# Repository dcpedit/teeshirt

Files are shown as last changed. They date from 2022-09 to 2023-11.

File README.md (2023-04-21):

<p align="center">
  teeshirt_logo
</p>

# TeeShirt Keyboard

teeshirt-6

TeeShirt is a ergonomic monoblock keyboard with a one-size-fits-some PCB design that supports 3 different sized builds: S, M, and L.

## Features

* [Size S](https://github.com/dcpedit/teeshirt/tree/master/small-build): case-less barebones keyboard build
* [Size M](https://github.com/dcpedit/teeshirt/tree/master/medium-build): custom slim acrylic case build
* [Size L](https://github.com/dcpedit/teeshirt/tree/master/large-build): standard 60% case (GH60 compatible) build
* Supports 1.5u and 1.25u thumb keys to reduce gap between keycaps
* Spacebars can be 2u or 1.5u for stab-less builds
* Center key can be swapped out for a rotary encoder
* Supports 128x32 OLED display
* Utilizes hot swap sockets
* Uses ProMicro MCU footprint: Elite-C, Nice!Nano, etc.

## Sponsors

The first revision of the PCB was sponsored by PCBWay, so a huge thanks to them for helping get this project off the ground.  Their KiCad plugin made it super easy to send the design directly to their site, where you can place the order and have it shipped out with just a few clicks.

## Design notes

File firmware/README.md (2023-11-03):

# TeeShirt Firmware

## Vial
Binary: `dcpedit_teeshirt_vial_fancy.hex`

Source: https://github.com/dcpedit/vial-qmk-dev/tree/vial/keyboards/dcpedit/teeshirt

## ZMK

Binary: `zmk.uf2`

Source: https://github.com/dcpedit/zmk/tree/dcpedit/app/boards/shields/teeshirt

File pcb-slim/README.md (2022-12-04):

# TeeShirt PCB

pcb-slim

The PCB automatically applies power to the VBUS pin, but if you want to also send power to the RAW pin (#24), you can short JP1.

pcb-back-1

If you're relocating the USB port to the upper left of the PCB for the large sized (60%) builds, make sure you also soldering in 5.1k resistors, as well as connecting the data pins on the PCB (D+/D-) to the data pins/pads to the MCU with wires.

bottom-2

For the small builds, the MCU can be mounted on the top side with headers.

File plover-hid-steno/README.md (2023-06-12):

# Small TeeShirt build and Plover

Keymap

I've put together some documentation for those who wanted to play around with stenography.  It took some tinkering to get ZMK working with Plover, so hopefully these instructions will be helpful to those who are looking to accomplish the same thing.

## ZMK firmware

https://github.com/dcpedit/zmk-plover/tree/plover-hid-hog-attempt/app/boards/shields/teeshirt

Make sure you're cloning the `plover-hid-hog-attempt` branch:
```
git clone -b plover-hid-hog-attempt https://github.com/dcpedit/zmk-plover
```

This is a fork of dnaq's implementation of the Plover HID protocol in ZMK.  You can read about it in the [official pull request here.](https://github.com/zmkfirmware/zmk/pull/962)  You can also clone his fork directly with the following command:
```
git clone -b plover-hid-hog-attempt https://github.com/dnaq/zmk
```

Follow the [ZMK environment setup](https://zmk.dev/docs/development/setup).  I highly recommend using VS Code & Docker.  For MacOS users, you may need to update `.devcontainer/DockerFile` with the following line for the container to start:
```
FROM --platform=linux/x86_64 docker.io/zmkfirmware/zmk-dev-arm:3.0
```

To run the build:
```
cd app
west build -b nice_nano_v2 -- -DSHIELD=teeshirt
```
Binary will be located here.
```
app/build/zephyr/zmk.uf2
```

If you're using a TeeShirt board, you can use my precompiled binary (`zmk.uf2`)

After loading the firmware, you can test it with the following website (by jthlim):
https://lim.au/#/software/plover-hid

## Macs with Intel chip

Plover requires the `hidapi` package, so you will need to install it with [Homebrew](https://brew.sh/).

```
brew install hidapi
```

## Macs with ARM chip (M1, M2)

The ARM version of `hidapi` package will not work, so you will need to install the Intel (x86) version of Homebrew and hidapi  [(source)](https://gist.github.com/progrium/b286cd8c82ce0825b2eb3b0b3a0720a0).

```
$ arch -x86_64 zsh
$ /bin/bash -c "$(curl -fsSL https://raw.githubusercontent.com/Homebrew/install/HEAD/install.sh)"
```

Add the following to your `~/.zshrc` file:
```
if [ "$(arch)" = "arm64" ]; then
    eval "$(/opt/homebrew/bin/brew shellenv)"
else
    eval "$(/usr/local/bin/brew shellenv)"
fi
```

Then install `hidapi`
```
$ source ~/.zshrc
$ brew install hidapi
```

## Plover software

Now download and install the Plover software: https://www.openstenoproject.org/plover/

If you're on MacOS, add "Plover" in System Settings > Security and Privacy > Input Monitoring.  Then disconnect and forget the bluetooth keyboard and reboot macOS. Clear the bluetooth setting on your keyboard and repeat the pairing process.  If that doesn't work, you may need to reflash.

Security and Privacy

## Plover HID Plugin

Download or clone https://github.com/dnaq/plover-machine-hid

Then switch to the directory where the plugin files are located.

```
cd plover-machine-hid
```

Follwing the [Plover instructions for installing plugins](https://plover.readthedocs.io/en/latest/plugins.html), run the command below (examples are for a Mac)

```
/Applications/Plover.app/Contents/MacOS/Plover -s plover_plugins install -e .
```

To list installed plugins

```
/Applications/Plover.app/Contents/MacOS/Plover -s plover_plugins list
```

## Configure Plover

Start the Plover application, click the **Configure** button, and then go to the **Machine** tab.  Select `Plover HID` in the **Machine** dropdown.

Double click on each of the **Action** cells in the right column and select the action that matches the left column.  Then click the **OK** button to go back to the main screen.

Configure

Select the `Plover HID` Machine and then click select `Enable`.

Plover-HID

## Reconnect plugin

Since ZMK boards will go to sleep after a period of inactivity, this reconnect plover plugin makes the experience more seamless when it wakes again:

https://github.com/tschulte/plover_auto_reconnect_machine

## Start typing!

And that's it!  The middle button on the TeeShirt will toggle the Plover layer on and off.  Here's a good resource if you're just starting out with Plover:

https://sites.google.com/site/learnplover/home

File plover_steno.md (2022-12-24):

# TeeShirt and Plover

I've put together some documentation for those who wanted to play around with stenography.  It took some tinkering to get ZMK working with Plover, so hopefully these instructions will save you some time.

## ZMK firmware

https://github.com/dcpedit/zmk-plover

This is a fork of dnaq's implementation of the Plover HID protocol in ZMK.  You can read about it in the [official pull request here.](https://github.com/zmkfirmware/zmk/pull/962)

The precompiled binary is in `firmware/plover_hid`.

After loading the firmware, you can test it with the following site:
https://lim.au/#/software/plover-hid

## Macs with Intel chip

Plover requires the `hidapi` package, so you will need to install it with [Homebrew](https://brew.sh/).

```
brew install hidapi
```

## Mac with ARM chip (M1, M2)

The ARM version of `hidapi` package will not work, so you will need to install the Intel (x86) version of Homebrew and hidapi.

```
$ arch -x86_64 zsh
$ /bin/bash -c "$(curl -fsSL https://raw.githubusercontent.com/Homebrew/install/HEAD/install.sh)"
```

```
$ brew install hidapi
```

## Plover software

Now download and install the Plover software: https://www.openstenoproject.org/plover/

## Plover HID Plugin

Download or clone https://github.com/dnaq/plover-machine-hid

Then switch to the directory where the plugin files are located.

```
cd plover-machine-hid
```

Follwing the [Plover instructions for installing plugins](https://plover.readthedocs.io/en/latest/plugins.html), run the command below (examples are for a Mac)

```
/Applications/Plover.app/Contents/MacOS/Plover -s plover_plugins install -e .
```

To list installed plugins

```
/Applications/Plover.app/Contents/MacOS/Plover -s plover_plugins list
```

## Configure Plover

Start the Plover application and click the **Configure** button and then go to the **Machine** tab.  Select **Plover HID** in the Machine dropdown.

Double click on each of the Action cells in the right column and select the action that matches the left column.  Then click the **OK** button to go back to the main screen.

Select the `Plover HID` machine and then click select **Enable**

Then

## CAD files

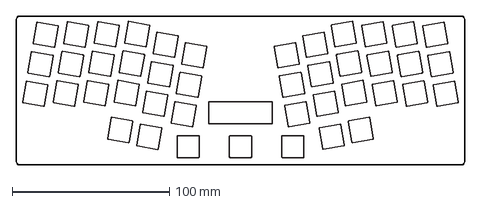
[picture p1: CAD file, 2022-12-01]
large-build/case-full.dxf
285.0 x 94.6 mm

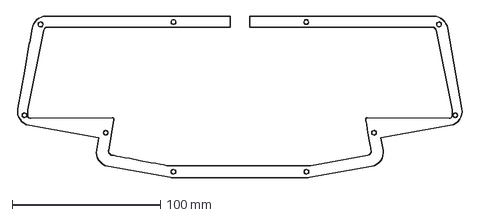
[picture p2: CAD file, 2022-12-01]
medium-build/case-slim.dxf
300.7 x 109.0 mm

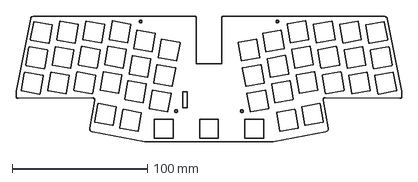
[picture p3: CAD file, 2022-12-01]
small-build/bare-stacked.dxf
285.0 x 92.5 mm

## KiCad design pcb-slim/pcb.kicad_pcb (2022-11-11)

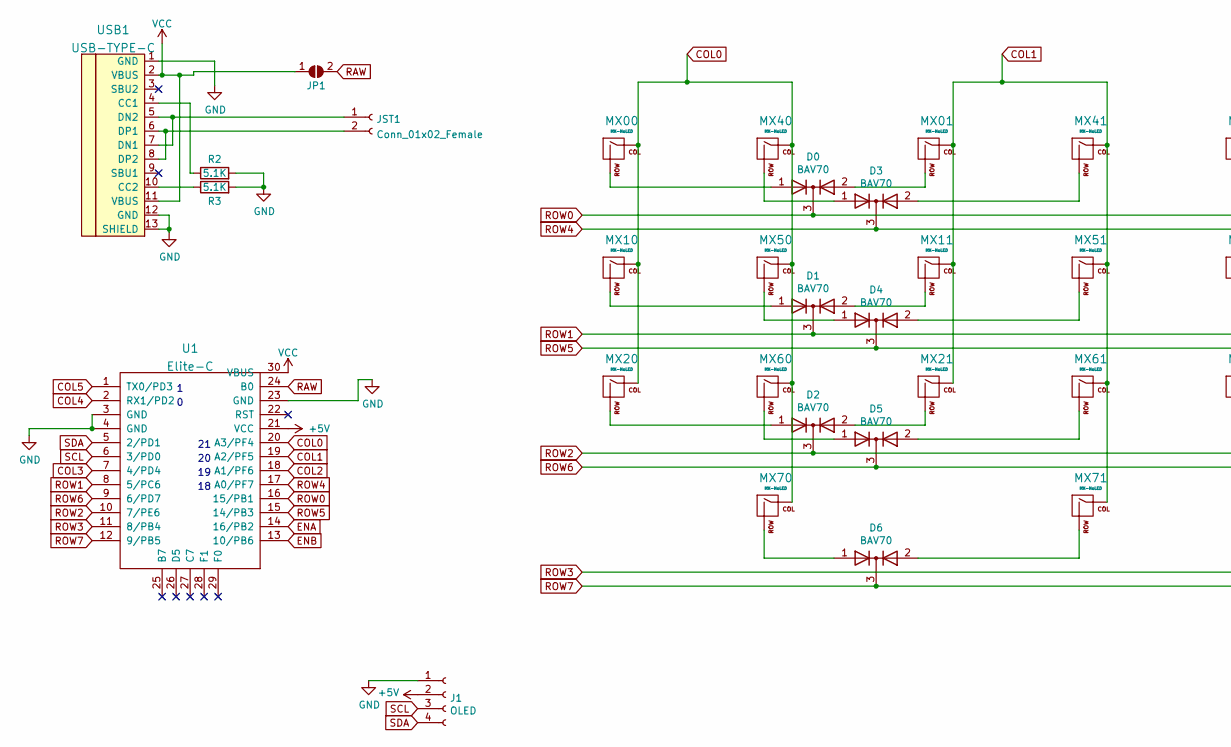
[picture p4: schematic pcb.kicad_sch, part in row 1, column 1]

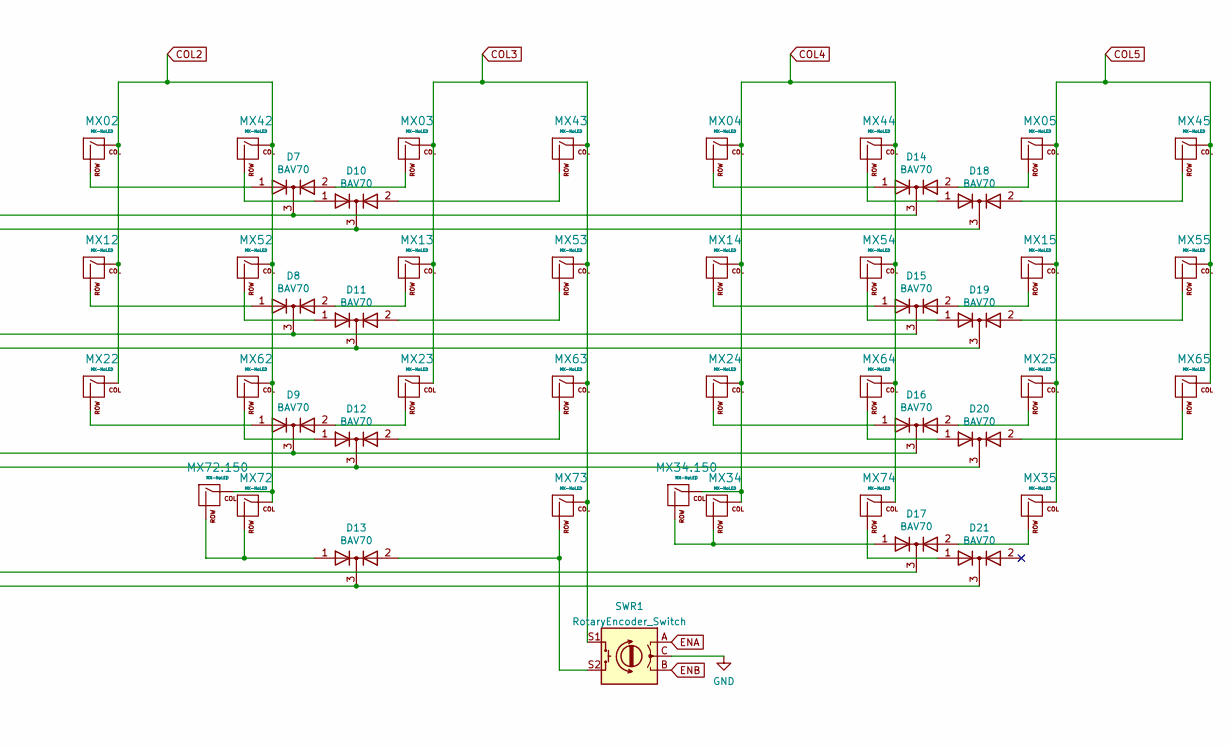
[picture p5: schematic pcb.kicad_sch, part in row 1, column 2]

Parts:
D0, D1, D2, D3, D4, D5, D6, D7, D8, D9, D10, D11, D12, D13, D14, D15, D16, D17, D18, D19, D20, D21: BAV70; SOT-23_Handsoldering
J1: OLED; SSD1306_OLED
JP1: SolderJumper_2_Open; SolderJumper-2_P1.3mm_Open_RoundedPad1.0x1.5mm
JST1: Conn_01x02_Female
MX00, MX01, MX02, MX03, MX04, MX05, MX10, MX11, MX12, MX13, MX14, MX15, MX20, MX21, MX22, MX23, MX24, MX25, MX34, MX34.150, MX35, MX40, MX41, MX42, MX43, MX44, MX45, MX50, MX51, MX52, MX53, MX54, MX55, MX60, MX61, MX62, MX63, MX64, MX65, MX70, MX71, MX72, MX72.150, MX73, MX74: MX-NoLED; MXOnly-1U-NoLED
R2, R3: 5.1K; R_0805_2012Metric_Pad1.20x1.40mm_HandSolder; LCSC C27834
SWR1: RotaryEncoder_Switch
U1: Elite-C
USB1: USB-TYPE-C

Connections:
+5V: J1.2, U1.21 (VCC)
COL0: MX00.1 (COL), MX10.1 (COL), MX20.1 (COL), MX40.1 (COL), MX50.1 (COL), MX60.1 (COL), MX70.1 (COL), U1.20 (A3/PF4)
COL1: MX01.1 (COL), MX11.1 (COL), MX21.1 (COL), MX41.1 (COL), MX51.1 (COL), MX61.1 (COL), MX71.1 (COL), U1.19 (A2/PF5)
COL2: MX02.1 (COL), MX12.1 (COL), MX22.1 (COL), MX42.1 (COL), MX52.1 (COL), MX62.1 (COL), MX72.1 (COL), MX72.150.1 (COL), U1.18 (A1/PF6)
COL3: MX03.1 (COL), MX13.1 (COL), MX23.1 (COL), MX43.1 (COL), MX53.1 (COL), MX63.1 (COL), MX73.1 (COL), SWR1.S1, U1.7 (4/PD4)
COL4: MX04.1 (COL), MX14.1 (COL), MX24.1 (COL), MX34.1 (COL), MX34.150.1 (COL), MX44.1 (COL), MX54.1 (COL), MX64.1 (COL), MX74.1 (COL), U1.2 (RX1/PD2)
COL5: MX05.1 (COL), MX15.1 (COL), MX25.1 (COL), MX35.1 (COL), MX45.1 (COL), MX55.1 (COL), MX65.1 (COL), U1.1 (TX0/PD3)
ENA: SWR1.A, U1.14 (16/PB2)
ENB: SWR1.B, U1.13 (10/PB6)
GND: J1.1, R2.2, R3.2, SWR1.C, U1.3 (GND), U1.4 (GND), U1.23 (GND), USB1.1 (GND), USB1.12 (GND), USB1.13 (SHIELD)
unnamed: D0.1 (A), MX00.2 (ROW)
unnamed: D0.2 (A), MX01.2 (ROW)
unnamed: D1.1 (A), MX10.2 (ROW)
unnamed: D1.2 (A), MX11.2 (ROW)
unnamed: D2.1 (A), MX20.2 (ROW)
unnamed: D2.2 (A), MX21.2 (ROW)
unnamed: D3.1 (A), MX40.2 (ROW)
unnamed: D3.2 (A), MX41.2 (ROW)
unnamed: D4.1 (A), MX50.2 (ROW)
unnamed: D4.2 (A), MX51.2 (ROW)
unnamed: D5.1 (A), MX60.2 (ROW)
unnamed: D5.2 (A), MX61.2 (ROW)
unnamed: D6.1 (A), MX70.2 (ROW)
unnamed: D6.2 (A), MX71.2 (ROW)
unnamed: D7.1 (A), MX02.2 (ROW)
unnamed: D7.2 (A), MX03.2 (ROW)
unnamed: D8.1 (A), MX12.2 (ROW)
unnamed: D8.2 (A), MX13.2 (ROW)
unnamed: D9.1 (A), MX22.2 (ROW)
unnamed: D9.2 (A), MX23.2 (ROW)
unnamed: D10.1 (A), MX42.2 (ROW)
unnamed: D10.2 (A), MX43.2 (ROW)
unnamed: D11.1 (A), MX52.2 (ROW)
unnamed: D11.2 (A), MX53.2 (ROW)
unnamed: D12.1 (A), MX62.2 (ROW)
unnamed: D12.2 (A), MX63.2 (ROW)
unnamed: D13.1 (A), MX72.2 (ROW), MX72.150.2 (ROW)
unnamed: D13.2 (A), MX73.2 (ROW), SWR1.S2
unnamed: D14.1 (A), MX04.2 (ROW)
unnamed: D14.2 (A), MX05.2 (ROW)
unnamed: D15.1 (A), MX14.2 (ROW)
unnamed: D15.2 (A), MX15.2 (ROW)
unnamed: D16.1 (A), MX24.2 (ROW)
unnamed: D16.2 (A), MX25.2 (ROW)
unnamed: D17.1 (A), MX34.2 (ROW), MX34.150.2 (ROW)
unnamed: D17.2 (A), MX35.2 (ROW)
unnamed: D18.1 (A), MX44.2 (ROW)
unnamed: D18.2 (A), MX45.2 (ROW)
unnamed: D19.1 (A), MX54.2 (ROW)
unnamed: D19.2 (A), MX55.2 (ROW)
unnamed: D20.1 (A), MX64.2 (ROW)
unnamed: D20.2 (A), MX65.2 (ROW)
unnamed: D21.1 (A), MX74.2 (ROW)
unnamed: R2.1, USB1.4 (CC1)
unnamed: R3.1, USB1.10 (CC2)
unnamed: JST1.1, USB1.5 (DN2), USB1.7 (DN1)
unnamed: JST1.2, USB1.6 (DP1), USB1.8 (DP2)
RAW: JP1.2 (B), U1.24 (B0)
ROW0: D0.3 (K), D7.3 (K), D14.3 (K), U1.16 (15/PB1)
ROW1: D1.3 (K), D8.3 (K), D15.3 (K), U1.8 (5/PC6)
ROW2: D2.3 (K), D9.3 (K), D16.3 (K), U1.10 (7/PE6)
ROW3: D17.3 (K), U1.11 (8/PB4)
ROW4: D3.3 (K), D10.3 (K), D18.3 (K), U1.17 (A0/PF7)
ROW5: D4.3 (K), D11.3 (K), D19.3 (K), U1.15 (14/PB3)
ROW6: D5.3 (K), D12.3 (K), D20.3 (K), U1.9 (6/PD7)
ROW7: D6.3 (K), D13.3 (K), D21.3 (K), U1.12 (9/PB5)
SCL: J1.3, U1.6 (3/PD0)
SDA: J1.4, U1.5 (2/PD1)
VCC: JP1.1 (A), U1.30 (VBUS), USB1.2 (VBUS), USB1.11 (VBUS)

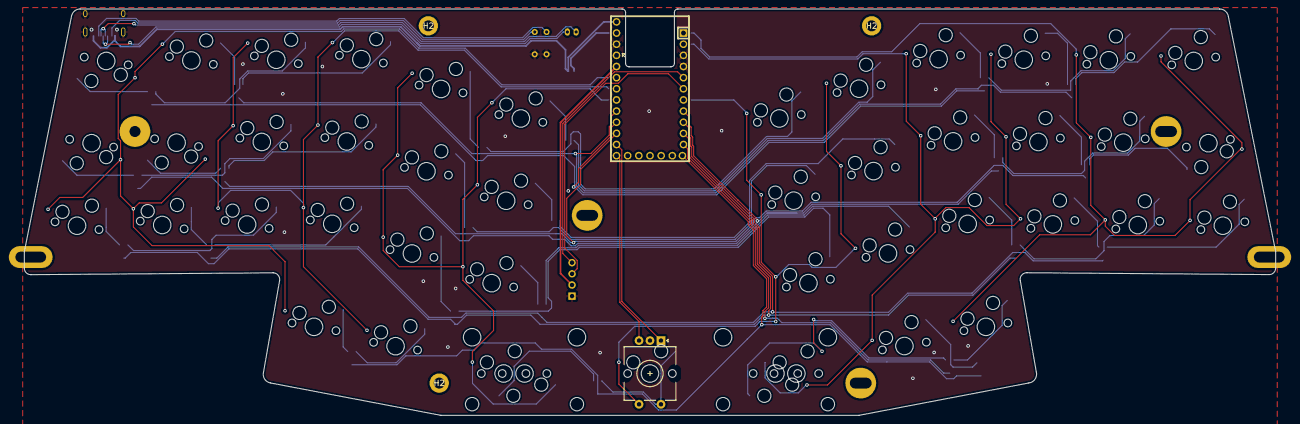
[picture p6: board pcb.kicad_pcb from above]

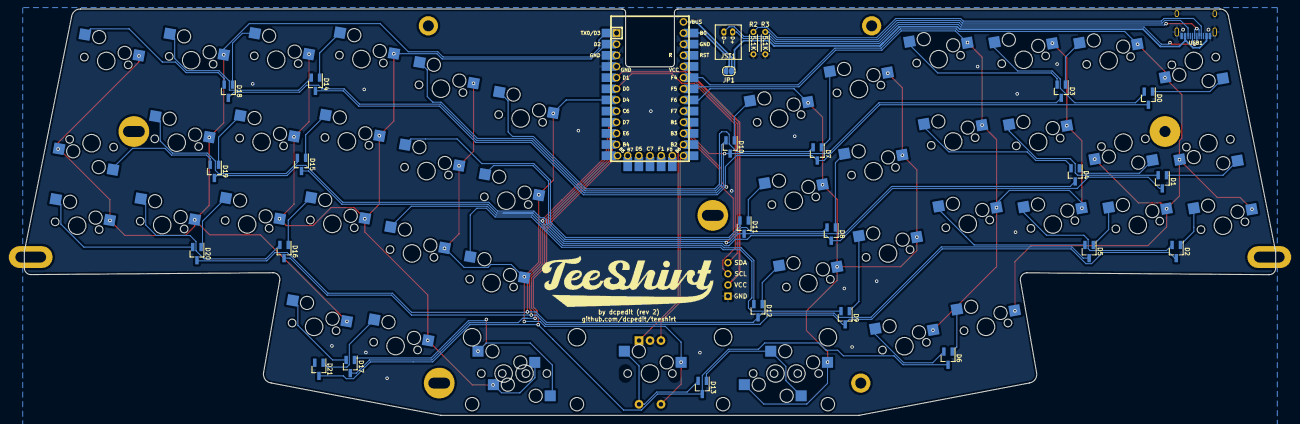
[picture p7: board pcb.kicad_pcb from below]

Board: 2 copper layers, 285.0 x 92.5 mm, 84 parts (28 on the bottom side), 69 nets.

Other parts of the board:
H2, H2#2, H2#3: (no value)
HOLE: VAL**; PKRH
HOLE#2, HOLE#4: VAL**; PKRH
HOLE#3, HOLE#5: VAL**; PKRHSL
HOLE#6: VAL**; PKRHC

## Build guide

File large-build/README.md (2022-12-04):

# Large Build Guide

Large-1

This guide is based on the exact build that is pictured above.  Feel free to customize it to your fit your needs.

## Components

| Part | Count | Description |
| ---- | ----- | --- |
| Elite-C | 1 | Microcontroller |
| USB port | 1 | TYPE-C-31-M-12 |
| Wires | 2 | Connects data lines to PCB |
| Pin | 1 | For power connection |
| 5.1k resistor| 2 | Through hole pulldown resistors for USB-C |
| Diodes | 22 | BAV70 SMD |
| Switch sockets | 42 | Kailh hot swap sockets |
| OLED | 1 | SSD1306 128x32 |
| Rotary encoder | 1 | EC11 |
| Encoder knob | 1 | No more than 20mm diameter |
| Plate foam | 1 | 3.5mm (or 1.5mm + 2mm) EVA foam |
| Bottom foam | 1 | thickness varies |
| Switch plate | 1 | 1.5mm acrylic |
| OLED window | 1 | 3mm transparent acrylic |
| Stabalizers | 2 | 2u PCB mount |
| Keycaps | 42 | 36x1u, 2x1.25u, 2x1.5u, 2x2u |

## Adobe Illustrator Layers

| Name | Description | Material |
| ---- | --- | --- |
| Window | OLED window | 3mm or 1.5mm transparent acrylic |
| Plate 2u | Switch plate for 2u spacebars | 1.5mm acrylic |
| Plate 1u | Switch plate for 1u or 1.5u spacebars | 1.5mm acrylic |
| Foam Plate | Switch plate foam | 3.5mm foam (ex: 1.5mm + 2mm EVA) |
| Foam Bottom | Case foam | Thickness depends on case (ex: 1mm EVA) |

## Assembly steps

Note that only the rotary encoder and OLED components are on the front of the PCB.  All other components are on the back.

### Solder USB-C port

Make sure you position the port on the back of the PCB.  Solder in the 4 port legs before doing the small pins.  For the pins, place some solder on your iron tip and lightly drag the solder across the small pads.  If you happen to brdige the pins, clean your iron tip and try to pick up the extra solder.

### Solder diodes

teeshirt_build-1

Place a dab of solder on the single bottom pad of the diode on the PCB.  Then using tweesers, position the diode so that the legs line up with the pads.  Then using the point of one tweeser leg, gently hold the top of the diode in place while melting the dab of solder that was placed on the bottom pad previously.  With the diode now held in position, solder the top two legs to their respective pads.

### Solder switch sockets

Place some solder on one of the hot swap socket pads.  There should ben enough solder to make a small mound.  Place the socket into position and melt the mound of solder that was previously added while pressing down on the center of the socket.  Be sure to avoid touching any metalic parts to prevent burns.  Keep the soldering iron on the pad long enough for the solder to flow around the socket connector (usually around 3 to 4 seconds).  Now solder the other socket connector to the pad.

### Solder 5.1k resistors

teeshirt_build-2

Bend the legs of each resistor and place them into position on the back of the PCB.  Orientation does not matter.  Bend the legs outwards to keep them in place, and flip the PCB over to the front to solder them in.  Clip protruding legs with flush cutters.

### Prep Data Wires

Strip both ends of 2 wires and solder them to the D+ and D- holes on the Elite-C.  Keep the wires and solder joints as flush as possible on the back side of the MCU.  I use flush cutters to snip off any of the wire that protrotrudes BEFORE soldering.  Then I use a minimal amount of solder to fill the hole but not create a mound that sticks too far out.

Tip: make sure the wire is long enough to reach the D+/D- holes on the PCB before cutting them.  Use different color wires to easily differentiate between positive and negative.

### Solder MCU

Move your MCU into position and place the power pin through the VBUS hole to make sure it's ligned up to the VBUS hole on the PCB.  Solder the Elite-C directly to the bottom of the PCB.  Then solder the data wires to the PCB making sure that D+ and D- match on both ends.

Tip: route wires so that they can lay as flat as possible against the MCU/PCB.

### Solder power pin to MCU

Place the power pin back into the VBUS hole on the MCU so that it goes all the way through the PCB.  Solder both sides of the pin and clip off the extra.  Don't use too much solder so that the pin can be clipped as close to the PCB as possible.

### Solder rotary encoder

Insert rotary into the front of the PCB and bend all the legs inwards.  After soldering the pins, you can also bend the 2 metal support flaps inwards as well.

### Solder OLED display

teeshirt_build-3

For this particular build, the OLED display is soldered right up against the PCB so that it's as low-profile as possible.  This allows for the OLED window to be attached directly onto the switch plate.  Using headers would add too much height to use a window, or would require a different window design which utilizes standoffs.  (There's only 5mm of space between the top of the PCB and the top of the switch plate)

Place a strip of electrical tape on the PCB where the OLED screen will touch the PCB.  Solder the connection pins to the OLED screen, or if they're already pre-soldered, remove the plastic spacer from the pins.  Place the OLED into position on the front of the PCB and flip it over while holding the display in place with your finger or with heat resistant tape.  Place just enough solder on one of the legs to hold in in place and check that the display is not crooked.  Once everything is straight, solder the other legs in place.

### Install stabalizers

teeshirt_build-4

### Place bottom foam into case

teeshirt_build-5

### Mount PCB into the case

teeshirt_build-6

### Lay plate foam on top of PCB

teeshirt_build-7

### Attach OLED window to switch plate

Using glue of your choice, place a dab of it on each corner and glue the window into position while making sure it's centered over the plate hole.

### Position switch plate on top of foam

teeshirt_build-8

### Install switches

teeshirt_build-9

### Install rotary encoder knob

### Install keycaps

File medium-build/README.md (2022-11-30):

# Medium Build Guide

Medium-1

This guide is based on the exact build that is pictured above.  Feel free to customize it to your fit your needs.

## Components

| Part | Count | Description |
| ---- | ----- | --- |
| Elite-C | 1 | Microcontroller |
| Diodes | 22 | BAV70 SMD |
| Switch sockets | 42 | Kailh hot swap sockets |
| OLED | 1 | SSD1306 128x32 |
| Rotary encoder | 1 | EC11 |
| Encoder knob | 1 | No more than 20mm diameter |
| Plate foam | 1 | 3.5mm (or 1.5mm + 2mm) EVA |
| Bottom foam | 1 | 1.5mm EVA |
| Switch plate | 1 | 1.5mm acrylic |
| Stabalizers | 2 | 2u PCB mount |
| Keycaps | 42 | 36x1u, 2x1.25u, 2x1.5u, 2x2u |
| Acrylic case layers | 7 | 3mm white acrylic (top & bottom layer is transparent gray)
| M2x13mm standoff | 10 | Case perimeter |
| M2x6mm standoff | 9 | PCB mount |
| M2x3mm screw | 9 | PCB mount bottom |
| M2x4mm screw | 19 | PCB mount top & case bottom |
| M2x8mm screw | 10 | Case top |
| Non-slip bottom | 1 | 1.5mm adhesive neoprene

## Adobe Illustrator Layers

| Name | Quantity | Material |
| ---- | --- | --- |
| #1 Top 1u Clear | 1 | 3mm transparent acrylic |
| #2 Top spacer | 1 | 3mm acrylic |
| #3 - #4 Mid spacer | 2 | 3mm acrylic |
| #5 - #6 Bottom spacer | 2 | 3mm acrylic |
| #7 Bottom | 1 | 3mm acrylic |
| Bottom Foam | 1 | 1.5mm EVA |
| Bottom Rubber | 1 | 1.5mm adhesive neoprene |
| Plate Foam | 1-2 | 3.5mm (or 1.5mm + 2mm) EVA |
| 2u Plate Floating | 1 | 1.5mm acrylic |

## Assembly steps

### Solder diodes

Place a dab of solder on the single bottom pad of the diode on the PCB.  Then using tweesers, position the diode so that the legs line up with the pads.  Then using the point of one tweeser leg, gently hold the top of the diode in place while melting the dab of solder that was placed on the bottom pad previously.  With the diode now held in position, solder the top two legs to their respective pads.

### Solder switch sockets

Place some solder on one of the hot swap socket pads.  There should ben enough solder to make a small mound.  Place the socket into position and melt the mound of solder that was previously added while pressing down on the center of the socket.  Be sure to avoid touching any metalic parts to prevent burns.  Keep the soldering iron on the pad long enough for the solder to flow around the socket connector (usually around 3 to 4 seconds).  Now solder the other socket connector to the pad.

### Solder MCU

Solder the Elite-C directly to the bottom of the PCB.

### Solder rotary encoder

Insert rotary into the front of the PCB and bend all the legs inwards.  After soldering the pins, you can also bend the 2 metal support flaps inwards as well.

### Solder OLED header

There's only 10mm of space between the PCB and the transparent acrylic top layer, so the OLED + header cannot exceed this height.  For this build, I had to dremel/sand the plastic part of the header down to about 7mm.  I also had to remove the plastic spacer on the OLED pins and clip the pins to fit into the shorter header.  Insert the display into the header and make sure the total height is under 10mm before soldering the header onto the front of the PCB.

### Install stabalizers

### Case assembly

teeshirt_m_build-1

* Attach the 10 M2x13mm standoffs around the perimeter of the bottom case layer with the M2x4mm screws
* Assemble 9 PCB mounts by screwing a M2x3mm screw into one end of a M2x6mm standoff.  Then take the mount assembly and slip it into the mount holes on the bottom case layer so that all the screw heads are on the bottom.
* Slip #5 - #6 bottom spacer layers over the perimeter standoffs
* Put the bottom foam into the case

teeshirt_m_build-2

* Mount the PCB into the case standoffs using M2x4mm screws

teeshirt_m_build-3

* Slip #3 - #4 mid spacer layers over the perimeter standoffs

teeshirt_m_build-4

* Put the plate foam onto the PCB
* Put the switch plate on top of the plate foam, making sure the switch holes are lined up
* Push all the switches into the hotswap sockets (note north vs. south facing)
* Insert OLED display into the header
* Slip #2 top spacer layer over the perimeter standoffs
* Slip #1 top clear layer over the perimeter standoffs
* Secure all case layers with the M2x8mm screws

### Install neoprene bottom

Remove the paper on the adhesive side of the neoprene, and carefully lay it over the bottom of the case. Start on one side while smoothing air bubbles out.  You may have to stretch the neoprene during this process to get the screw heads to line up with the holes.

bottom-1

### Install keycaps

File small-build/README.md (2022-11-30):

# Small Build Guide

teeshirt-8

This guide is based on the exact build that is pictured above.  Feel free to customize it to your fit your needs.

## Components

| Part | Count | Description |
| ---- | ----- | --- |
| Nice!Nano | 1 | Microcontroller |
| Battery | 1 | 3.7v litium (ex: 301230) |
| MCU headers | 2 | 1x12 pin (Mill Max 310-93-112-41-001000) |
| MCU pins | 24 | round (Mill Max 3320-0-00-15-00-00-03-0) |
| Diodes | 22 | BAV70 SMD |
| Switch sockets | 43 | Kailh hot swap sockets |
| OLED display | 1 | SSD1306 128x32 |
| OLED header | 1 | 1x4 pins |
| Switch plate | 1 | 1.5mm acrylic |
| OLED/MCU guard | 1 | 3mm transparent acrylic |
| Bottom plate | 1 | 3mm acrylic |
| M2x5mm standoff | 13 | 9 for the bottom, and 4 for the guard |
| M2x4mm screws | 26 | Wafer head screws |
| Stabalizers | 2 | 2u PCB mount |
| Keycaps | 43 | 37x1u, 2x1.25u, 2x1.5u, 2x2u |

## Adobe Illustrator Layers

| Name | Description | Material |
| ---- | --- | --- |
| Clear guard | OLED/MCU window/guard | 3mm transparent acrylic |
| 2u Switch Plate | Switch plate for 2u spacebars | 1.5mm acrylic |
| 1u Switch Plate | Switch plate for 1u or 1.5u spacebars | 1.5mm acrylic |
| Bottom Plate | Keyboard bottom | 3mm acrylic |

## Assembly steps

This particular build does not use foam, but the foam layers are included in the Illustrator file.

### Solder diodes

Place a dab of solder on the single bottom pad of the diode on the PCB.  Then using tweesers, position the diode so that the legs line up with the pads.  Then using the point of one tweeser leg, gently hold the top of the diode in place while melting the dab of solder that was placed on the bottom pad previously.  With the diode now held in position, solder the top two legs to their respective pads.

### Solder switch sockets

Place some solder on one of the hot swap socket pads.  There should ben enough solder to make a small mound.  Place the socket into position and melt the mound of solder that was previously added while pressing down on the center of the socket.  Be sure to avoid touching any metalic parts to prevent burns.  Keep the soldering iron on the pad long enough for the solder to flow around the socket connector (usually around 3 to 4 seconds).  Now solder the other socket connector to the pad.

### Solder OLED header

There's only 10mm of space between the PCB and the clear acrylic guard, so the OLED + header cannot exceed this height.  For this build, I had to dremel/sand the plastic part of the header down to about 7mm.  I also had to remove the plastic spacer on the OLED pins and clip the pins to fit into the shorter header.  Insert the display into the header and make sure the total height is under 10mm before soldering the header onto the front of the PCB.

### Solder MCU headers and pins

As mentioned before, there's only 10mm of space between the PCB and the clear acrylic guard, so the total hight of the MCU after it's been mounted can't exceed this hight.  Place the two 1x12 headers on the top of the PCB and solder them into place.  

Now place a piece of masking tape over the headers and insert the pins into each hole.  Place the MCU over the pins (components facing down towards the PCB) and make sure it's seated flush against the masking tape.  You can now solder the pins.  Once the joints have cooled, SLOWLY wedge your fingertips into the gap under the MCU on BOTH sides until it's free from the header.  Pulling too hard and unevenly may bend the pins when one side suddenly becomes free.  With the MCU removed, you can now remove the masking tape.

### Attach battery

I'd suggest first placing the batter under the installed MCU to see what orientation makes the most sense.  For my build, it was with the battery wires exiting on the top left of the battery.  If you wish to cut the battery wires to the correct lenght, you can do that now, or just tuck the extra wire under the MCU.

With the MCU removed, solder the red wire into the B+ hole, and black wire into the B- hole.  Note that this build did not incorporate a power switch.

You can now reattach the MCU to the board.

### Install stabalizers

### Mount PCB into bottom plate

Attach 9 M2x5 standoffs to the bottom plate using the 4mm screws.  Now secure the PCB to the standoffs using another 9 screws.

bottom-2

### Install standoffs for clear guard

Attach 4 M2x5 to the switch plate using the 4mm screws.  Don't attach the actual clear guard yet since that's done at the end of the build.

### Install the switch plate and switches

Using your finger or a "switch plate support fork" to hold the plate 3.5mm away from the PCB, insert your switches.  It's important to keep that 3.5mm gap through the entire plate so that your switches are able to "snap" into place.

### Attach OLED display

Insert the OLED display into the header.  You can optional place a piece of foam tape under the display to hold it in place if it feels unstable.

### Install clear acrylic guard

Secure the guard to the standoffs using 4 M2x4 screws.

### Install keycaps

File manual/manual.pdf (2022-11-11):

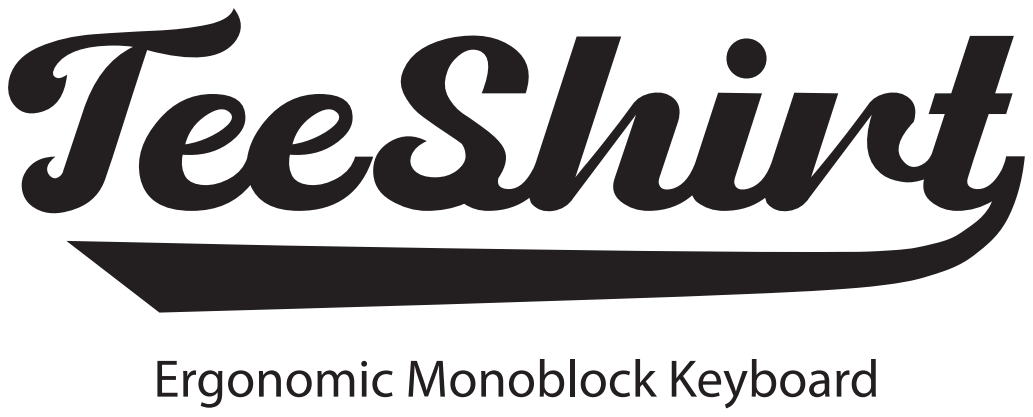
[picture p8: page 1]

Ergonomic Monoblock Keyboard

# Base Layer (0)

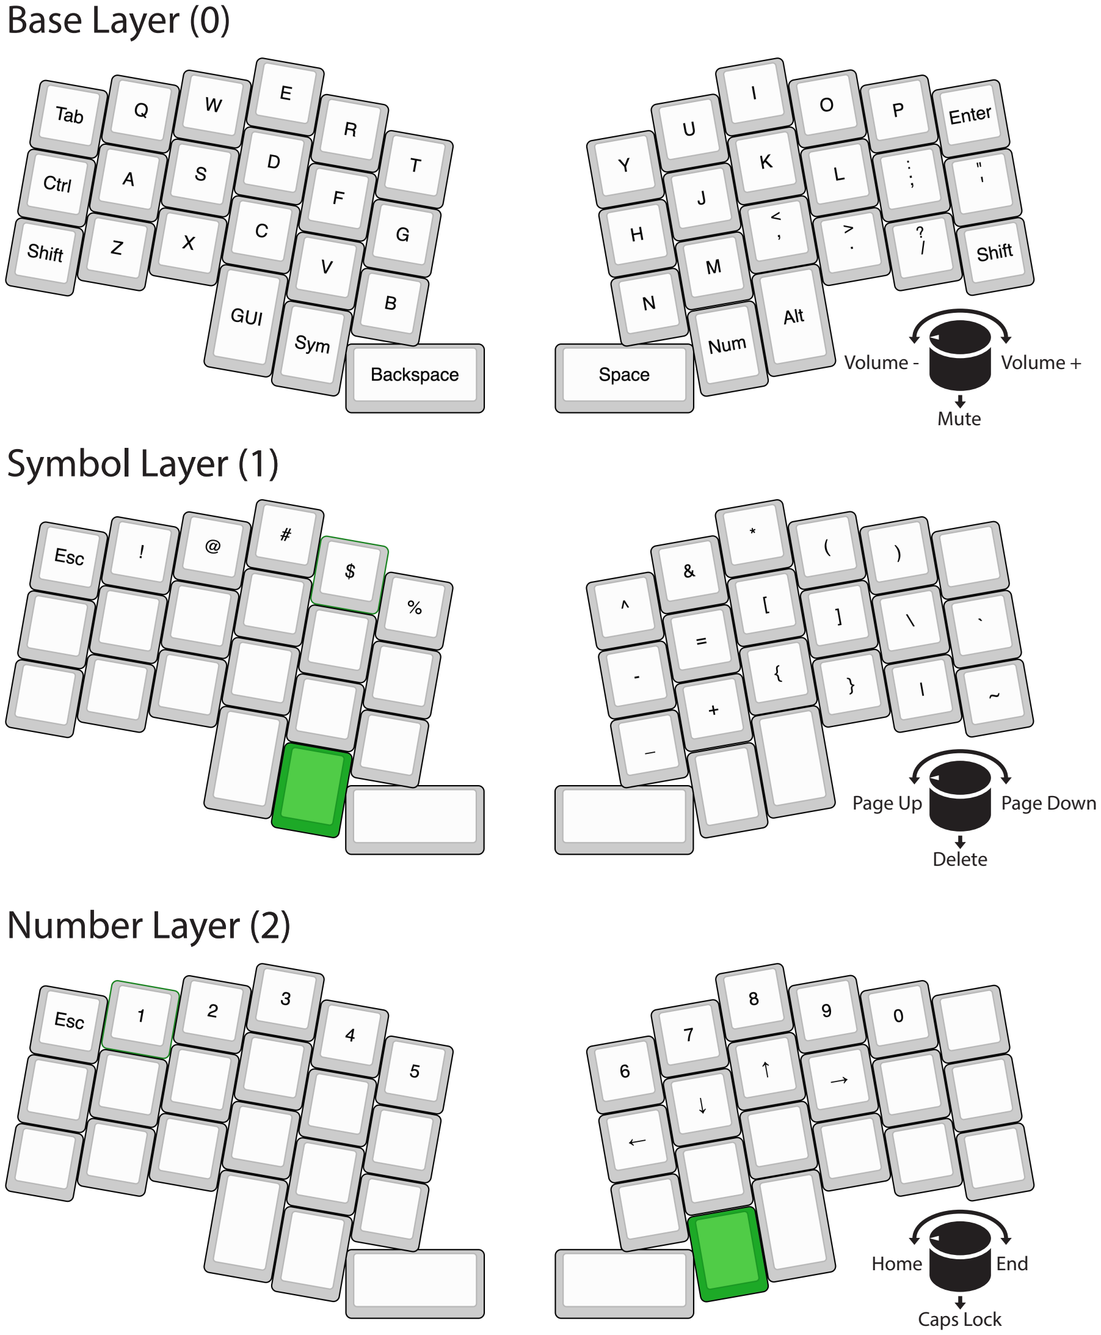
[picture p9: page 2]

# Symbol Layer (1)

# Number Layer (2)

Volume - | Volume +

Mute

Page Up | Page Down

Delete

Home | End

Caps Lock

# Extra Layer (3)

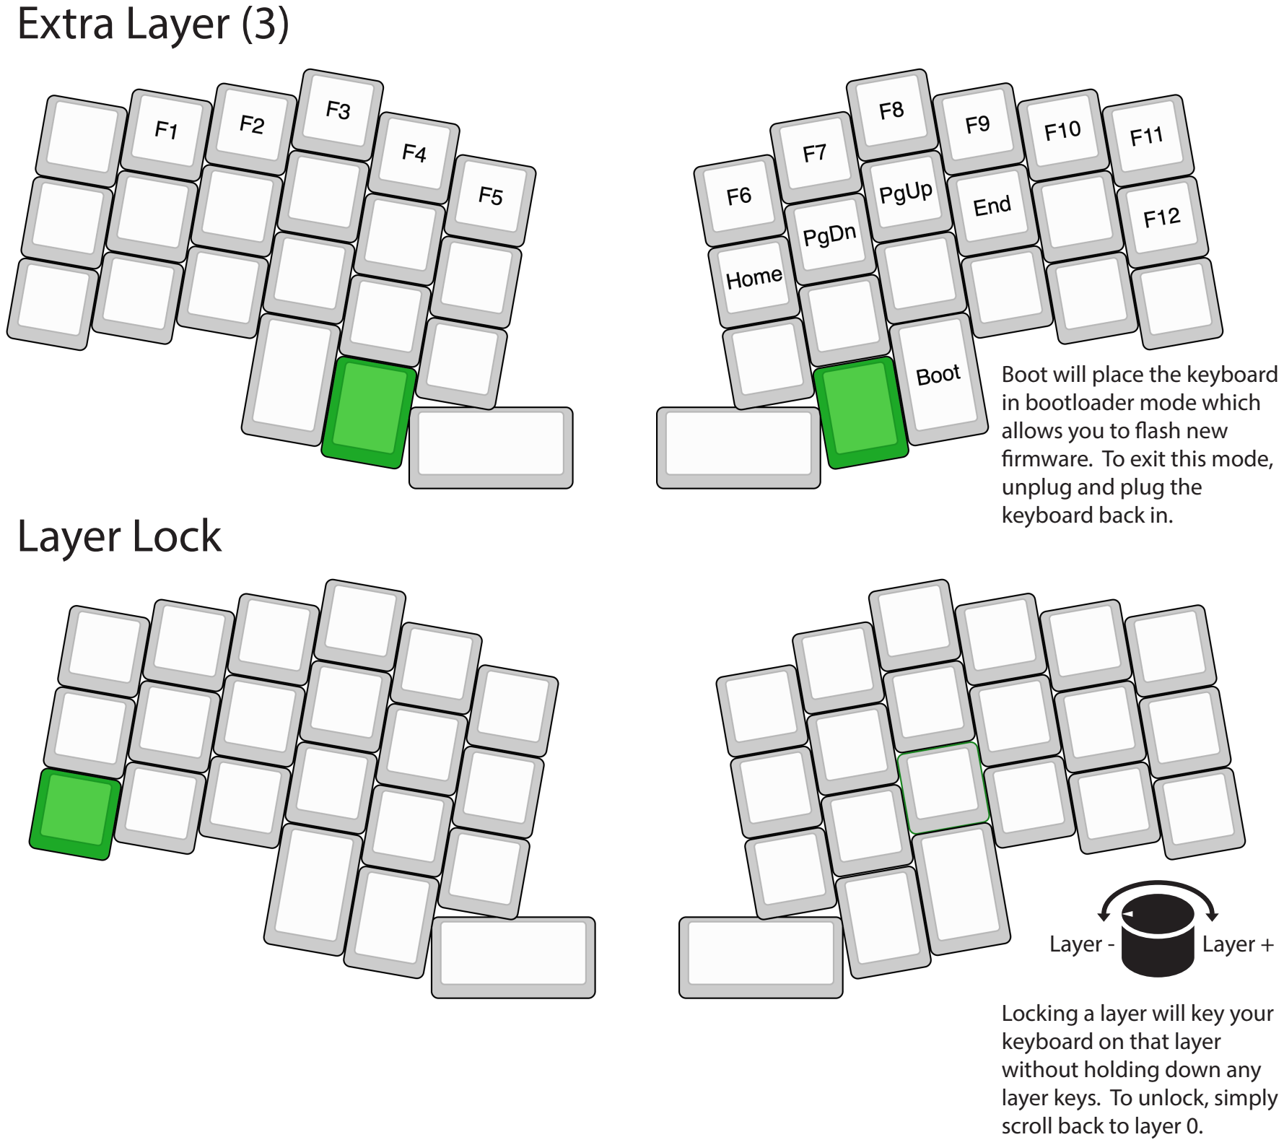
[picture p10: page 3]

Layer - | Layer +

# Layer Lock

Locking a layer will key your keyboard on that layer
without holding down any
layer keys. To unlock, simply scroll back to layer 0.

Boot will place the keyboard in bootloader mode which
allows you to ash new
rmware. To exit this mode, unplug and plug the
keyboard back in.

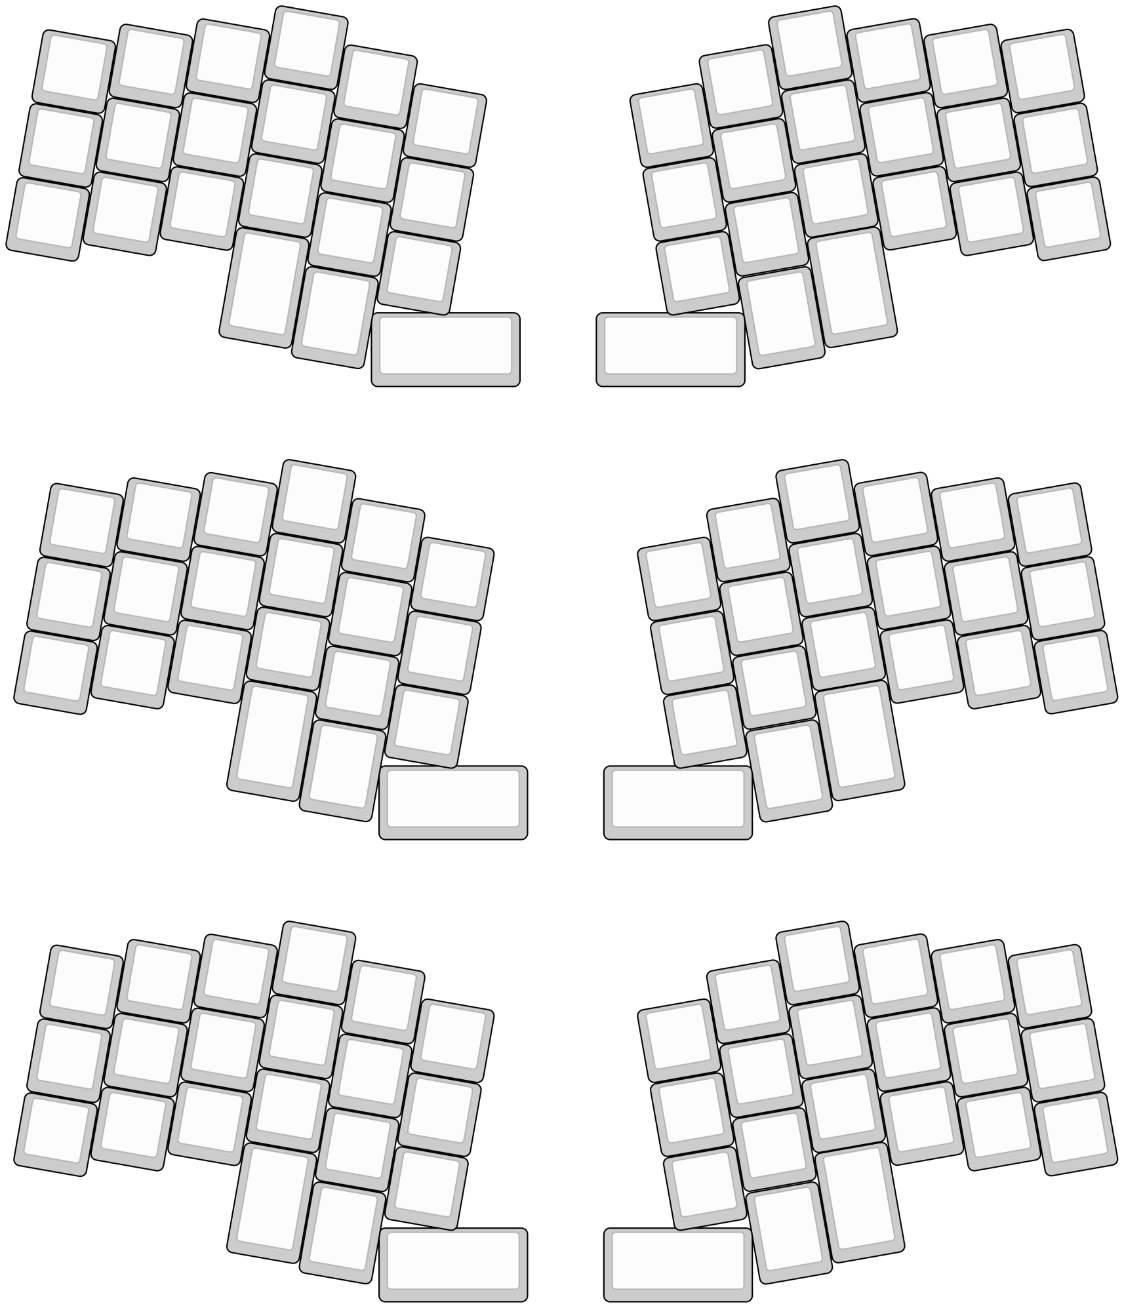
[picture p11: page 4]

# Remap Keys with Vial

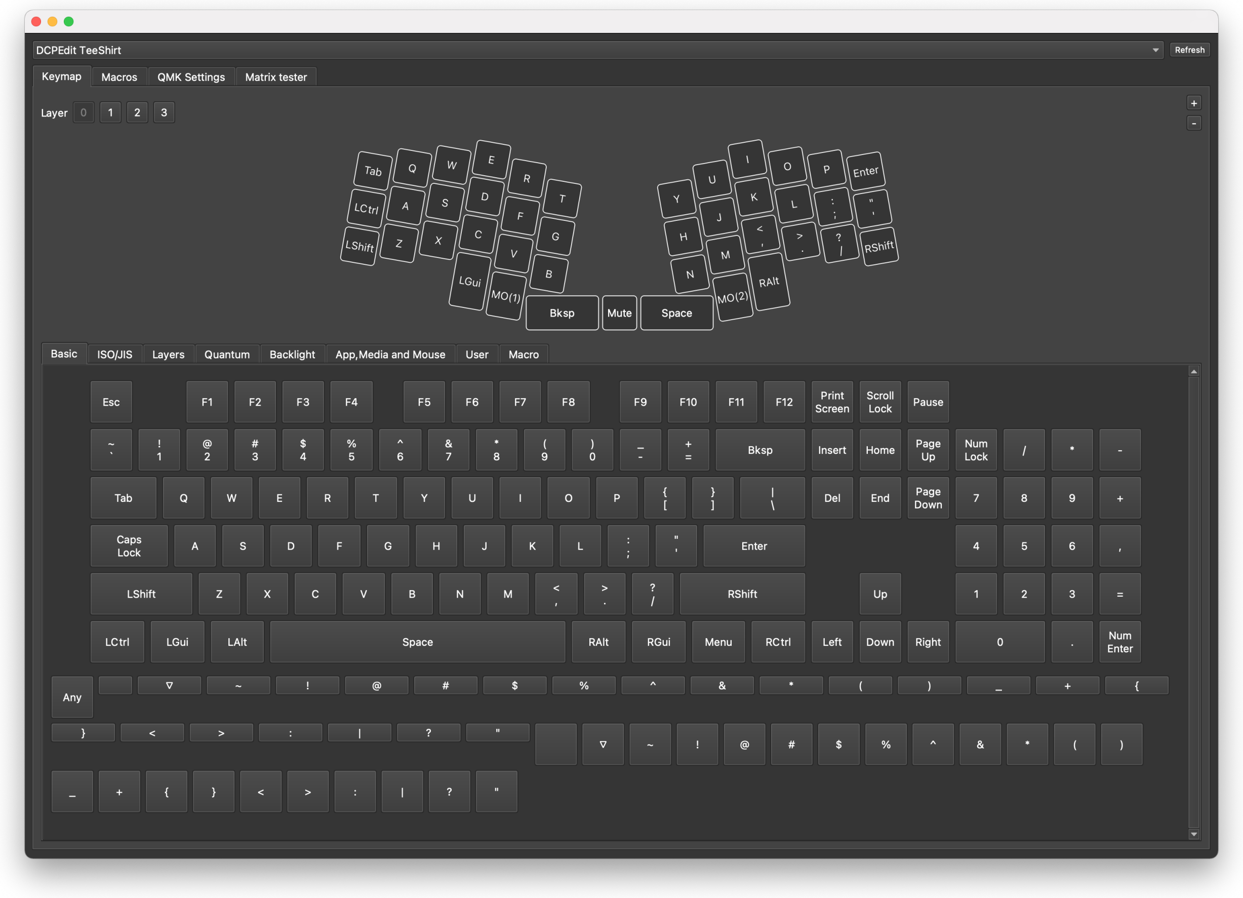
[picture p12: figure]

# https://get.vial.today

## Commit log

2022-10-01 Case updates
    [pcb.kicad_pcb, plate.kicad_pcb, plate.kicad_sch]
2022-11-11 Manual and bare case files
    [pcb.kicad_pcb]
2022-11-26 Add readme
    [plate-slim.kicad_pcb, plate.kicad_pcb]
2022-11-26 Remove experimental files
    [pcb.kicad_pcb, pcb.kicad_sch, template.kicad_pcb]
2022-11-30 Add PCB readme
2022-12-01 Add gerbers
2022-12-01 Export to DXF
    [bare-stacked.dxf, case-full.dxf, case-slim.dxf]
